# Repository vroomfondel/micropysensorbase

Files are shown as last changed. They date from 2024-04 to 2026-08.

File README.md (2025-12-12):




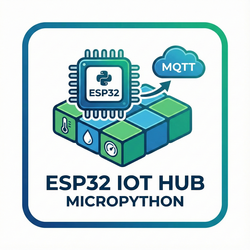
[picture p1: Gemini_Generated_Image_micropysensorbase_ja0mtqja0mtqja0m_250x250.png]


# Some esp32 micropython sensor projectbase

Project containing base-logic / configurable boilerplate for connecting sensors via esp32 via mqtt to nodered/whatever

## Description

Initial/Main project goal was to setup a device (or to be precise a couple of those) to be put in drainage 
systems in the field(s) to monitor the water-levels in the drainage system shafts and thus the proper functioning 
of the drainage pumps and their triggering.

### Extended description

This repository provides a reusable MicroPython-based foundation for building ESP32 sensor nodes that publish
telemetry to an MQTT broker for downstream processing in Node-RED, time-series storage (e.g., InfluxDB), and
monitoring/alerting (e.g., Uptime Kuma). The reference implementation focuses on hydrostatic water-level
monitoring for agricultural drainage shafts and pump supervision, but the architecture is intentionally modular
to support additional sensors and use-cases.

- Purpose and scope
  - Enable rapid provisioning of one or more ESP32 devices that read sensor data (current, voltage, illumination,
    custom analog values, etc.) and reliably publish messages via Wi‑Fi/MQTT.
  - Provide configuration-driven setup (Wi‑Fi, MQTT, I2C, sensor parameters) without reflashing firmware.
  - Offer an opinionated example flow for transforming and visualizing the data using Node‑RED and InfluxDB,
    as well as basic uptime/health monitoring.

- Architecture at a glance
  - Device firmware: MicroPython running on ESP32 with boot/main entry points and a small set of modules for
    connectivity, configuration, sensor I/O (e.g., INA226), and MQTT publishing.
  - Transport: MQTT (tested with Mosquitto) using topic conventions that are easy to consume from Node‑RED.
  - Backend/visualization: Example Node‑RED flows for normalization/calibration and routing to time-series
    storage and monitoring dashboards (InfluxDB, Uptime Kuma). Grafana can be added if desired.

- Hardware reference (water‑level monitoring)
  - ESP32 board with Wi‑Fi
  - INA226-based current/voltage measurement and a DC‑DC boost converter (XL6009/XL6019) to power 24 V sensors
  - Hydrostatic water level sensor (e.g., TL‑136)
  - Optional custom PCB (KiCAD files provided) and simple printed enclosure (FreeCAD/STL provided)

- Software components
  - Wi‑Fi management with retry and configurable credentials
  - MQTT client wrapper for robust publish/subscribe behavior on lossy links
  - INA226 measurement driver and helpers for shunt/expected‑amps configuration
  - Simple logging and diagnostics utilities suitable for constrained devices

- Data flow (typical)
  1) Sensor read cycle on the ESP32 collects samples (e.g., current/voltage correlated to water level)
  2) Values are formatted and published to MQTT topics
  3) Node‑RED consumes topics, applies calibration/offsets, and forwards to InfluxDB
  4) Uptime‑Kuma (or similar) monitors device and pump activity for alerting

- Configuration
  - Central JSON config (`esp32config.json` or `esp32config.local.json`) governs Wi‑Fi networks, MQTT broker
    credentials, I2C pin mapping, and sensor specifics (shunt value, expected current range, etc.).
  - Behavior can be adapted per device without code changes by distributing a device‑local JSON file.

- Reliability and operations
  - Designed to run unattended in outdoor enclosures; on boot, devices connect, read, and publish on a schedule.
  - Example Node‑RED flows include basic normalization and can be extended for fault detection.
  - Power draw of pumps can be correlated using separate smart plugs (e.g., Tasmota) to verify actuation events.

- Security considerations
  - Use unique MQTT credentials per device and, where possible, TLS‑enabled brokers.
  - Isolate the IoT network segment and restrict broker access to trusted clients.

- Extensibility
  - Add new sensors by implementing lightweight drivers and publishing to the existing topic structure.
  - Swap storage/visualization backends with minimal changes on the server side.

## Getting Started

### Dependencies

#### hydrostatic water-level monitoring :: hardware / environment
  * hydrostatic water level sensor TL-136
  * esp32
  * INA226
  * XL6009 DC-DC boost converter (TL-136 wants 24V which will be created by this converter 
    from the voltage/current supplied by the esp32's voltage(regulator))
  * wiring / breadboard / soldering iron
  * waterproof box (used this one in the end: https://www.amazon.de/gp/product/B0751QPFKM)

#### **(Update 2025-11-09)** KiCAD :: PCB :: hydrostatic water-level monitoring :: hardware / environment
  * KiCAD project files for PCB creation (used https://aisler.net/ for this): [kicad_ina226_xl6019_esp32_EXPORT.zip](PCB/kicad_ina226_xl6019_esp32_EXPORT.zip)
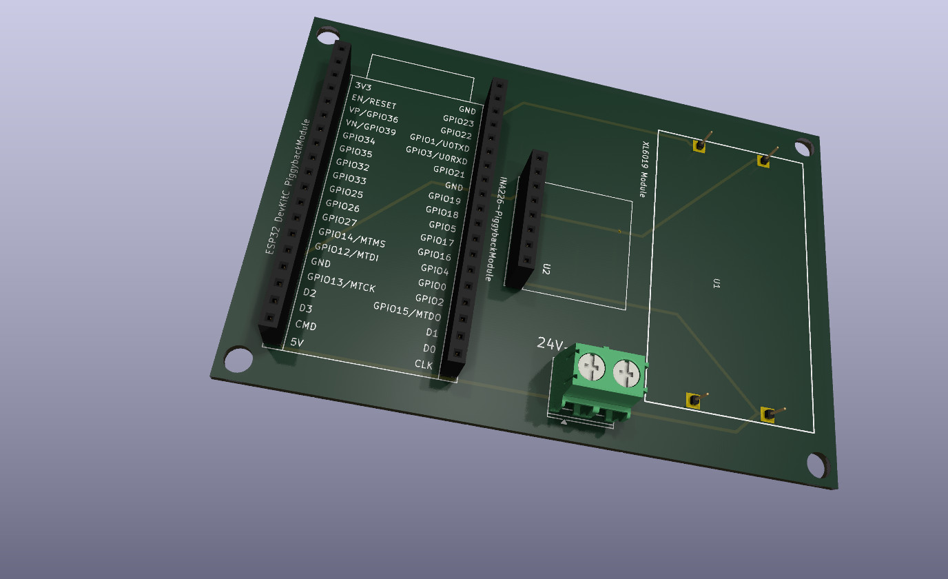
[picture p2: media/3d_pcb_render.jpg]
  * [](media/3d_pcb_render.jpg)
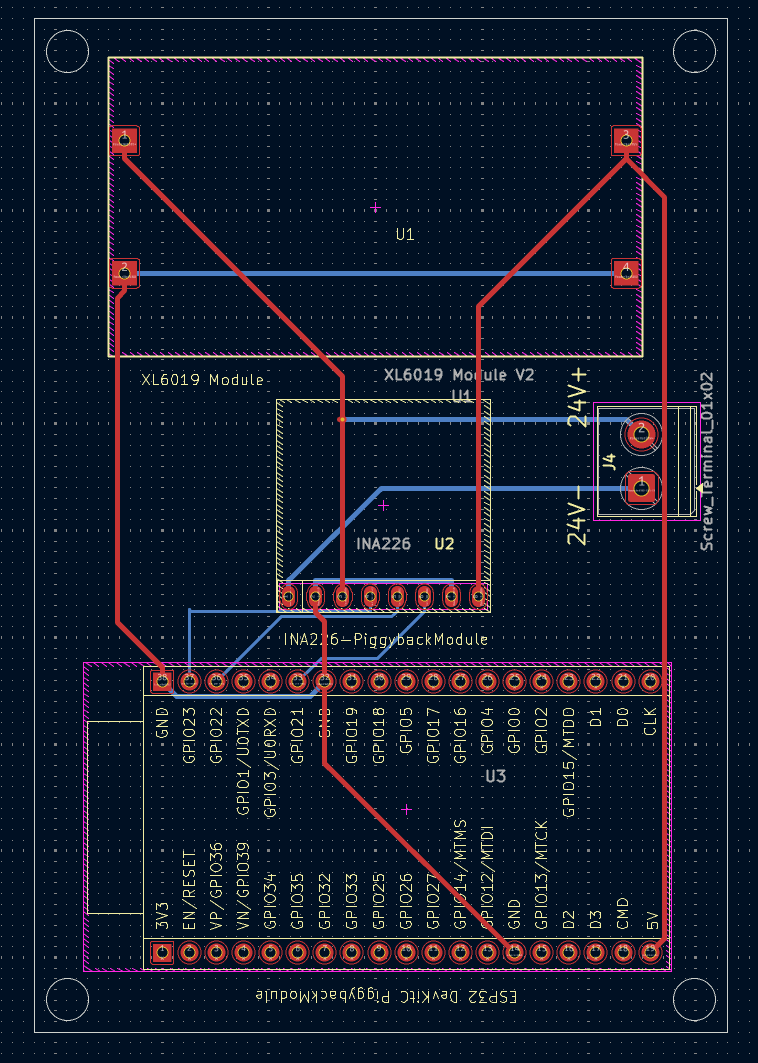
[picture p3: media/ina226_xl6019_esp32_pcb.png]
  * [](media/ina226_xl6019_esp32_pcb.png)
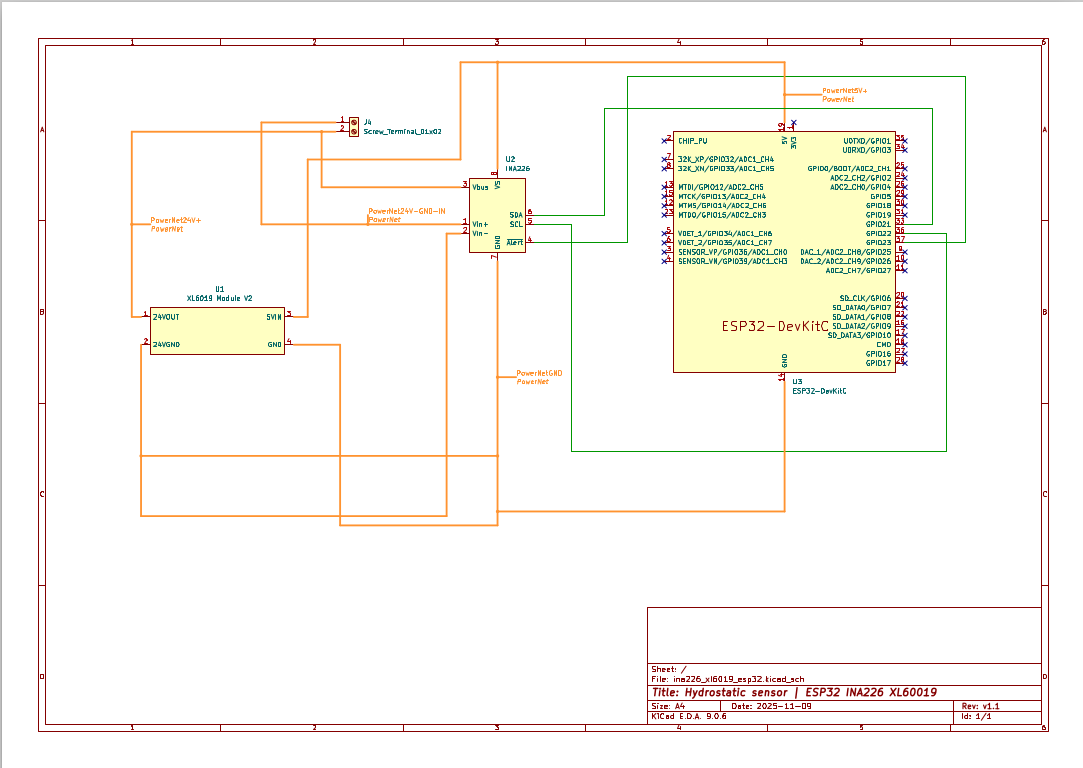
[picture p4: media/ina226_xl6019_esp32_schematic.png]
  * [](media/ina226_xl6019_esp32_schematic.pdf)
  * Received Board:<br/>
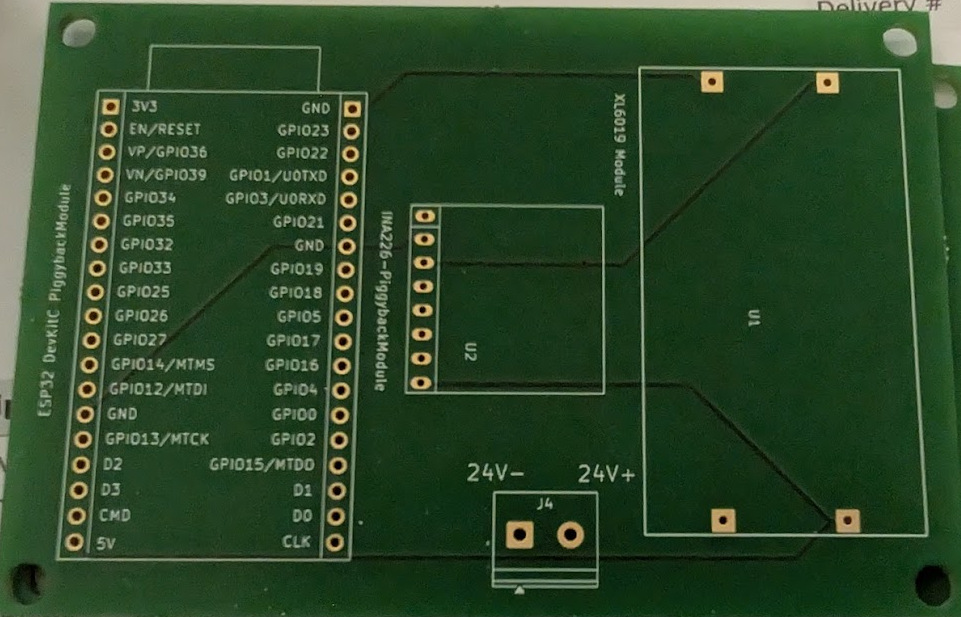
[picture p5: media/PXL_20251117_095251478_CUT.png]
    [](...)
  * Soldered+Assembled (broke one unused socket from the pin header):<br/>
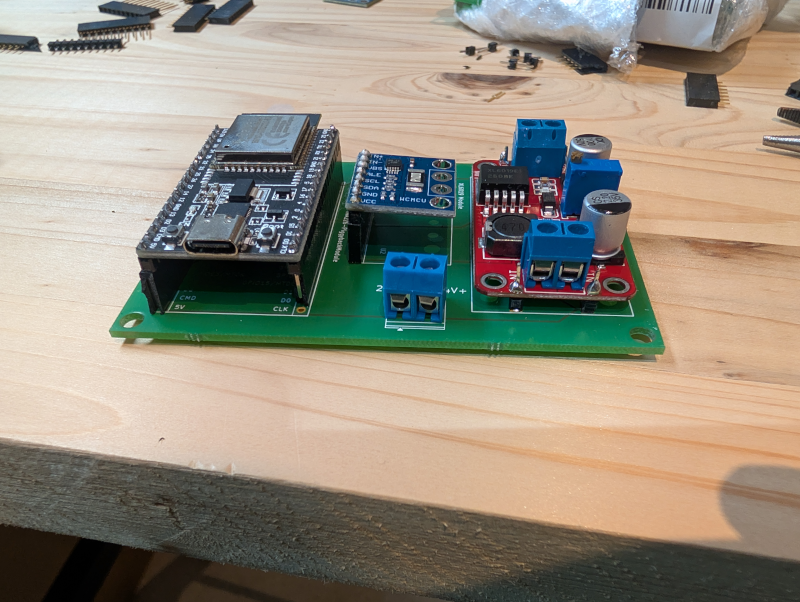
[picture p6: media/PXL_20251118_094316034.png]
    [](...)
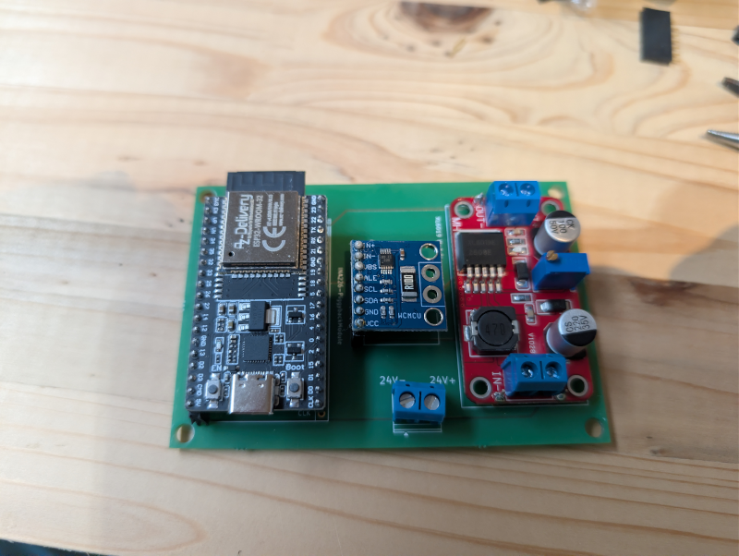
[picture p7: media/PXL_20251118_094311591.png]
    [](...)

#### **(Update 2025-11-22)** FreeCAD :: PCB :: Enclosure
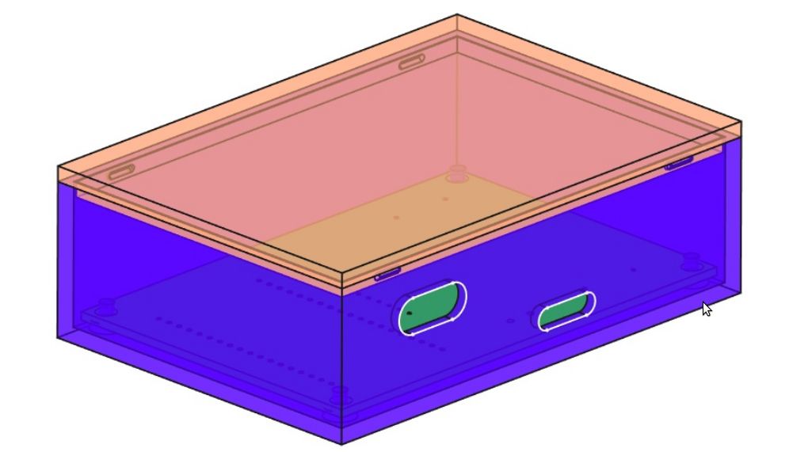
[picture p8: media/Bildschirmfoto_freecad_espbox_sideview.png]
  * [](media/esp32ina226pcbbox-sideview.pdf)
  * [esp32ina226pcbbox.FCStd](media/esp32ina226pcbbox.FCStd)
  * [esp32ina226pcbbox-BoxBase.stl](media/esp32ina226pcbbox-BoxBase.stl)
  * [esp32ina226pcbbox-BoxLid.stl](media/esp32ina226pcbbox-BoxLid.stl)

#### software / environment
  * wifi
  * installed mqtt-server (we used a local mosquitto instance for that purpose)
  * not needed, but pretty much the sense of it all: installed monitoring solution (we chose uptime-kuma)
  * installed node-red (used for some data mapping for monitoring the levels in uptime-kuma and 
    normalizing data (also used for applying "calibration"-/offset-data gathered beforehand))
  * installed influxdb (used for storing data over time and also for displaying 
    metrics (i do not really like to configure grafana - which is of course a wonderful tool))

#### Notes
* Could also be adapted to be used via esp-now -> but that would need quite hefty (but manageable) adaption 
  in regards to the mqtt-logic
* nodered-screenshot does not contains flow for monitoring the power-draw/-usage by the pumps which are connected 
  via a tasmota-enabled switchable socket (nous-A1T)

### Installing

* install a fresh version of micropython on an esp32 with wifi capabilities 
* copy over all files found in this repo to the device
* either adapt esp32config.json or create a copy of esp32config.json named as esp32config.local.json and adapt settings therein such as:
  * wifi-networks credentials
  * mqtt-broker credentials
  * enable i2c and set pins appropriately
  * enable INA226 and set shunt and expected amps appropriately 
  * create proper logic in node red/monitoring in uptime-kuma

### Executing program

* since the code is placed in boot.py and main.py just booting/resetting the esp32 should make this work

## Authors

Contributors names and contact info

* This repo's owner
* Other people mentioned/credited in the files

## Version History

* -0.42
    * there will be no proper versioning
    * earlier versions used INA219, but INA226 seems to be 
      more accurate and can additionally/also monitor voltage on the high side whilst 
      monitoring current on the low side.

## License

This project is licensed under the LGPL where applicable/possible License - see the [LICENSE.md](LICENSE.md) file for details.
Some files/part of files could be governed by different/other licenses and/or licensors, 
such as (e.g., but not limited to) [MIT](LICENSEMIT.md) | [GPL](LICENSEGPL.md) | [LGPL](LICENSELGPL.md); so please also 
regard/pay attention to comments in regards to that throughout the codebase / files / part of files.

## Acknowledgments

Inspiration, code snippets, etc.
* please see comments in files for that

## some pictures of it
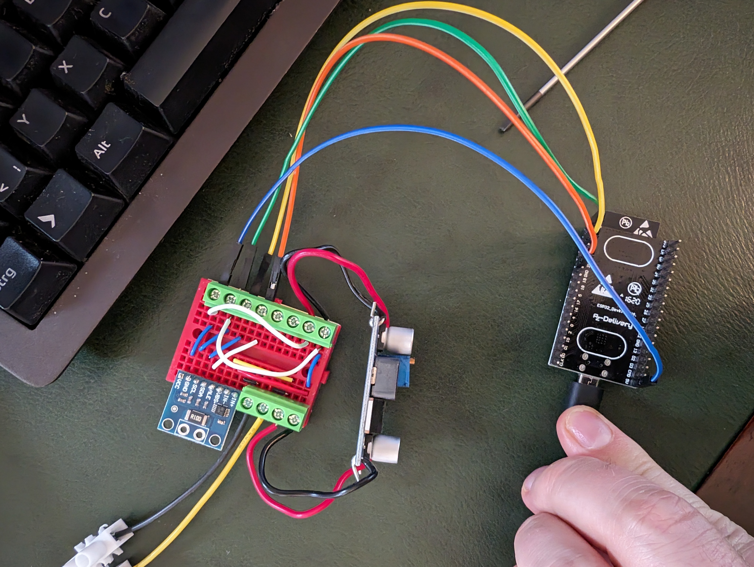
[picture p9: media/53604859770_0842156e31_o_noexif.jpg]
* [](media/53604859770_0842156e31_o_noexif.jpg)
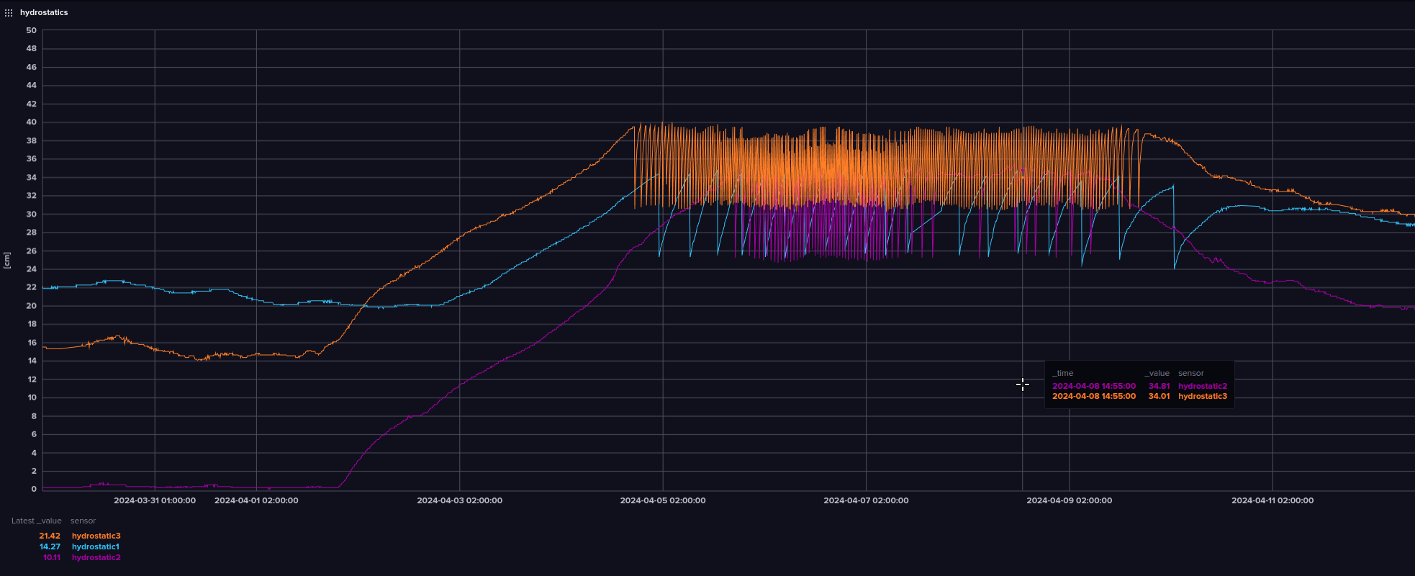
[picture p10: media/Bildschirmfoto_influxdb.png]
* [](media/Bildschirmfoto_influxdb.png)
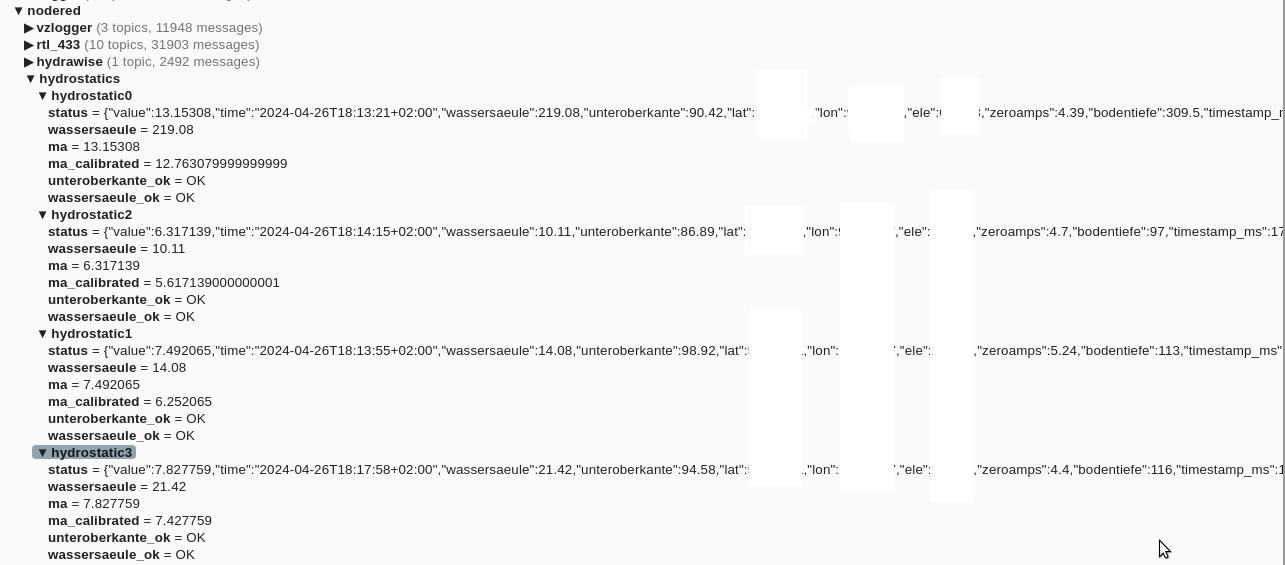
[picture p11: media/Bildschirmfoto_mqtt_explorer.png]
* [](media/Bildschirmfoto_mqtt_explorer.png)
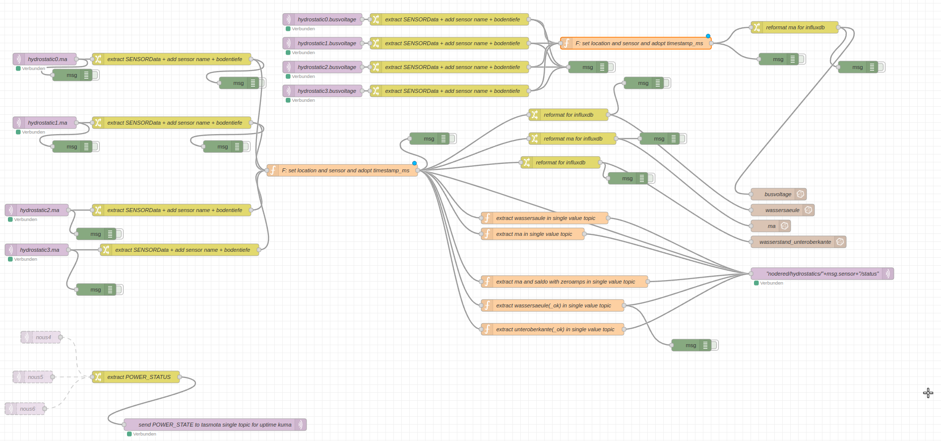
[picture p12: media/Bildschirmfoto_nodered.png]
* [](media/Bildschirmfoto_nodered.png)
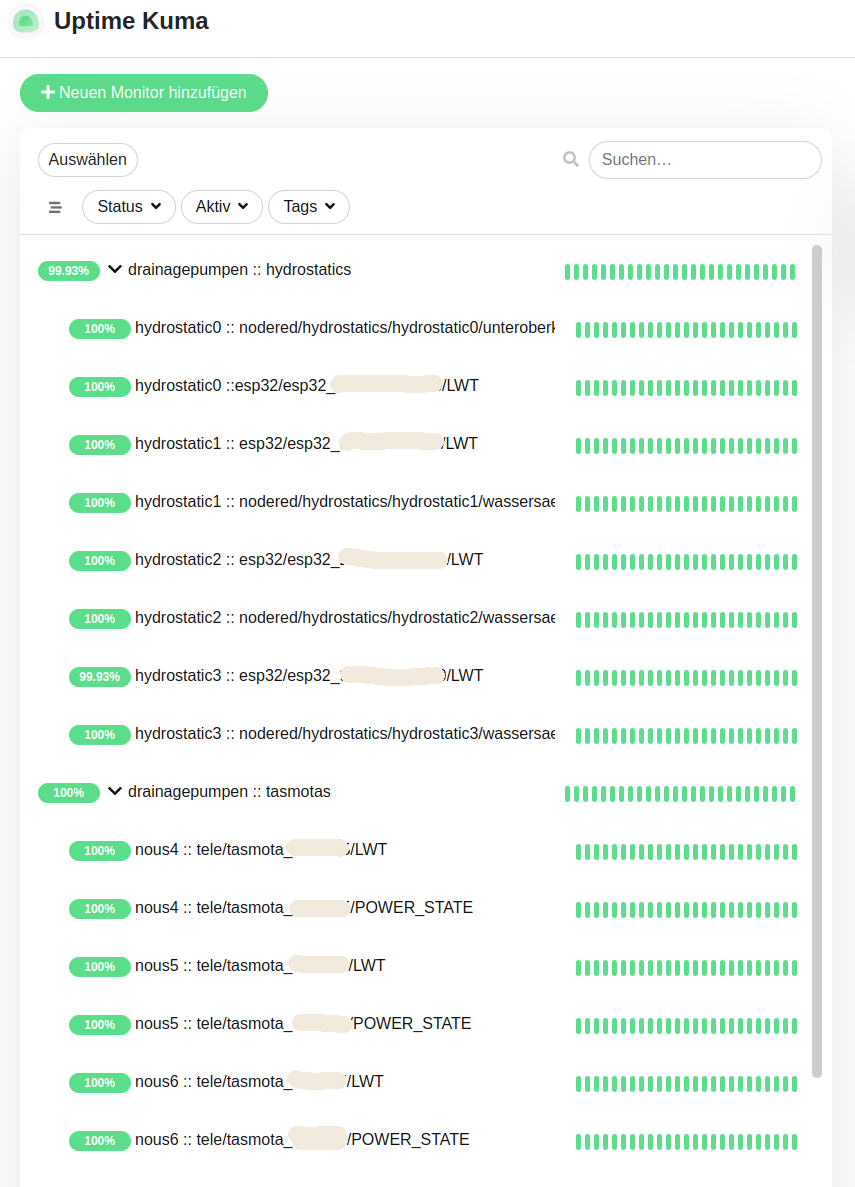
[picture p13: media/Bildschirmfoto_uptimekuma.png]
* [](media/Bildschirmfoto_uptimekuma.png)

#### btw. removing (relevant) exif-data from jpg-files should be quite easy
* ```for i in *jpg ; do exif -o ${i%.jpg}_noexif.jpg --remove $i ; done```

## TODO
* could make it pull needed files from this repo based on actual enable config-options
* exception-handling // stacktrace-printing has a lot of duplicated code throughout the codebase
* use more subflows in nodered and not just copy-paste custom-nodes :slightly_frowning_face:
* provide (fritzing?!) wiring diagram maybe ?!
* make a 3d printed enclosure which better suits the circuitry (at the moment I just 
  threw that in an plastik bag into the outdoor-box)
* make a PCB

## "Bonus content"
### tasmota-rules used on the switchable socket
* ```{"Rule1":{"State":"ON","Once":"OFF","StopOnError":"OFF","Length":258,"Free":253,"Rules":"ON Time#Minute|5 DO BackLog WebQuery http://somehost.in.the.internet.de/ GET ENDON ON WebQuery#Data=Done DO Publish stat/tasmota_112233/CONNECTIVITY OK ENDON ON WebQuery#Data$!Done DO BackLog AP 0 ; Delay 400; Publish stat/tasmota_112233/CONNECTIVITY FAILED ENDON"}}```
* ```{"Rule2":{"State":"ON","Once":"OFF","StopOnError":"OFF","Length":313,"Free":198,"Rules":"ON Power1#state=1 DO var1 ON ENDON ON Power1#state=0 DO var1 OFF ENDON ON system#boot do Backlog Power1 ON; var1 ON; Publish2 tele/tasmota_112233/POWER_STATE %var1% ENDON ON Time#Minute|1 DO Publish2 tele/tasmota_112233/POWER_STATE %var1% ENDON on Energy#Power>0 do Publish tele/tasmota_112233/POWER %value% endon"}}```
* ```{"Rule3":{"State":"ON","Once":"ON","StopOnError":"OFF","Length":216,"Free":295,"Rules":"on Energy#Power>=10 do Publish tele/tasmota_112233/POWERTRIGGER 1 endon on Energy#Power<10 do Publish tele/tasmota_112233/POWERTRIGGER 0 endon on Energy#Power<=0.001 do Publish tele/tasmota_112233/POWER %value% endon"}}```

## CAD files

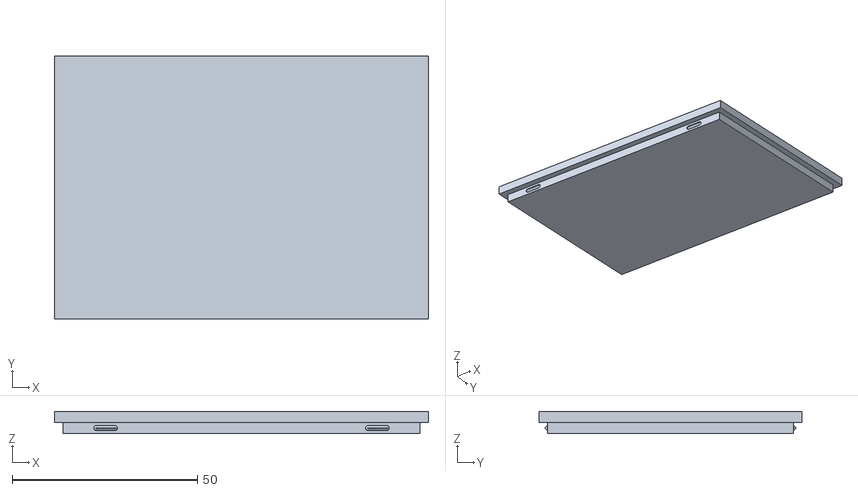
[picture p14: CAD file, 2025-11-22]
media/esp32ina226pcbbox-BoxLid.stl
101.0 x 71.0 x 6.00

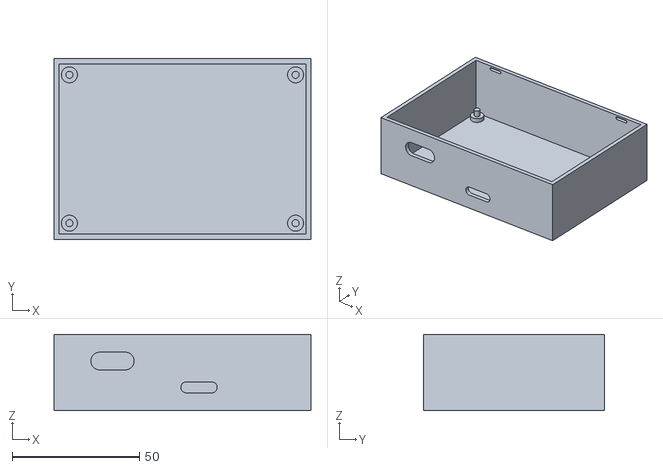
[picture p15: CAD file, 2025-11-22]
media/esp32ina226pcbbox-BoxBase.stl
101.0 x 71.0 x 30.0

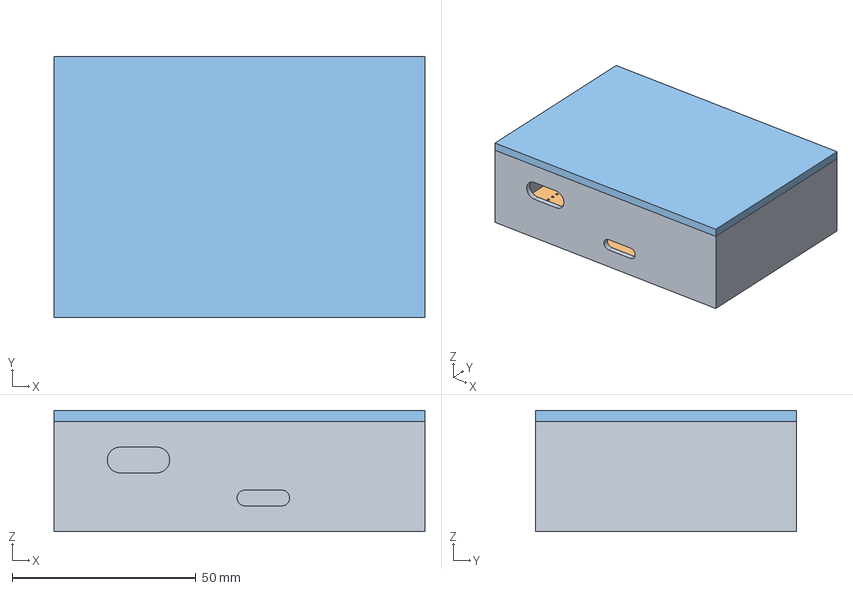
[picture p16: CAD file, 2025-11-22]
media/esp32ina226pcbbox.FCStd
101.0 x 71.0 x 33.0 mm
BoxBase
Pcb_31e5
BoxLid

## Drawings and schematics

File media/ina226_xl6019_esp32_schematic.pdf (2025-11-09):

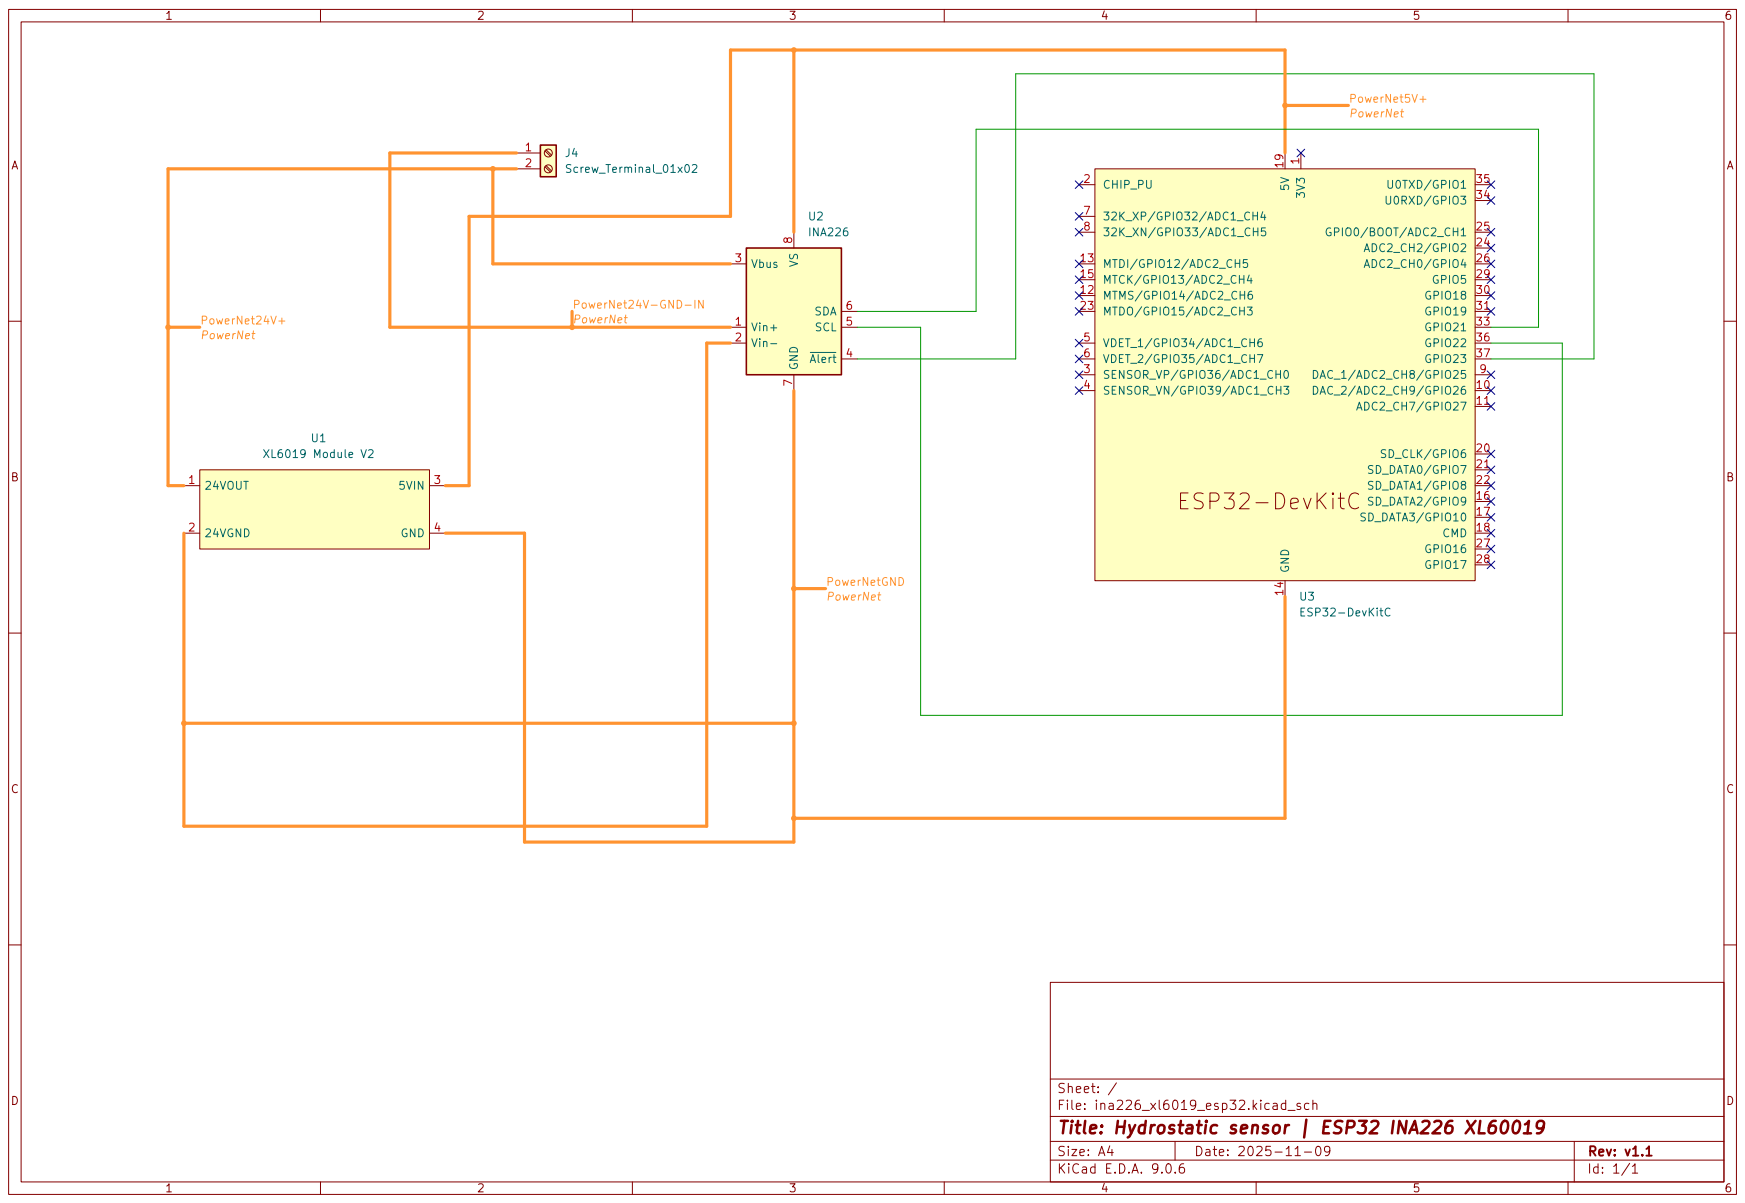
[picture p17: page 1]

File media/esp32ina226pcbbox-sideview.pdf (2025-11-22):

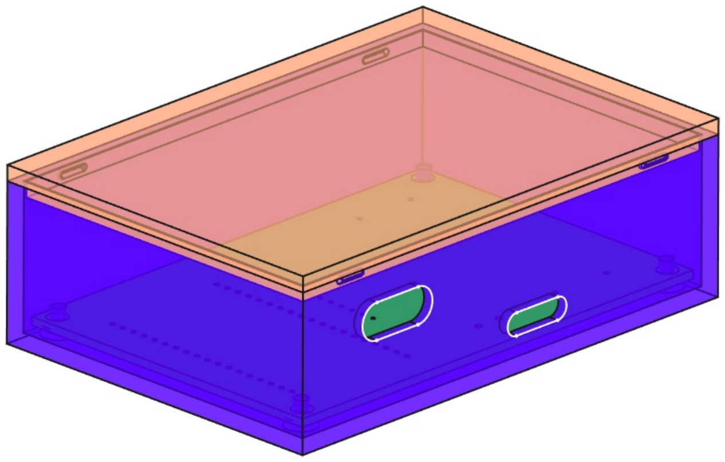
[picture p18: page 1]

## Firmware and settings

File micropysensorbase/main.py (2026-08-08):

import gc
import io
import sys

import micropython

from . import logging, time
from .time import sleep  # type: ignore[attr-defined]
from machine import Timer, WDT
import machine

from . import mqttwrap
from . import wifi
from . import config

import _thread

DISABLED_AUTO_SETUP: bool = False

logger = logging.get_logger(__name__)
logger.setLevel(logging.INFO)

if __name__ in config.get_config_data_dict(config.data, "loglevel"):
    melv: int|None = logging.get_log_level_by_name(
        config.get_config_data_str(config.get_config_data_dict(config.data, "loglevel"), "main"))
    if melv is not None:
        logger.setLevel(melv)

mainc: int = 0
logger.debug(f"main.py::{mainc}::STARTING")
mainc += 1


DISABLE_INET: bool = False

if "disable_inet" in config.data and config.get_config_data_bool(config.data, "disable_inet"):
    DISABLE_INET = True

if "disable_autosetup" in config.data:
    if config.get_config_data_bool(config.data, "disable_autosetup"):
        DISABLED_AUTO_SETUP = True
        logger.info(f"{DISABLED_AUTO_SETUP=} ENABLED")
    else:
        logger.info(f"{DISABLED_AUTO_SETUP=}")
else:
    logger.info(f"{DISABLED_AUTO_SETUP=} since not found in config")


msgtimer: Timer = Timer(0)
measuretimer: Timer = Timer(1)
reboottimer: Timer = Timer(2)
# esp32: four hardware-timers available

lock: _thread.LockType | config.DummyLock = config.DummyLock(name="main", loglevel=logging.INFO)
WATCHDOG: WDT|None = None

def reboot_callback(_: object=None) -> None:
    micropython.schedule(reboot_trigger, None)


def reboot_trigger(_: object=None) -> None:
    timestring: str = time.getisotimenow()
    logger.info(f"{timestring}::rebooting...")
    if mqttwrap is not None:
        mqttwrap.publish_one(
            topic=mqttwrap.get_feed("loggingfeed"),
            msg=f"rebooting at {timestring}",
            retain=True,
            qos=1,
            reset_if_mqtt_fails=True
        )
    machine.reset()


def check_msgs(_: object=None) -> None:
    global lock, DISABLE_INET, WATCHDOG

    if WATCHDOG:
        WATCHDOG.feed()

    if DISABLE_INET:
        return

    logger.debug("check_msgs")

    if lock.locked():
        logger.debug("main.py()::check:msgs::already LOCKED...")
        return

    acquired: bool = False
    try:
        acquired = lock.acquire()
        # timeout not implemented https://github.com/micropython/micropython/issues/3332
    except Exception as ex:
        _out = io.StringIO()
        sys.print_exception(ex)
        sys.print_exception(ex, _out)

        logger.error(_out.getvalue())

    gc.collect()

    if acquired:
        logger.debug("main.py()::check:msgs::lock acquired...")
        try:
            #with lock:
            logger.debug("main.py()::check:msgs::LOCK acquired...")
            wifi.ensure_wifi_catch_reset(reset_if_wifi_fails=True, watchdog=WATCHDOG)
            if WATCHDOG:
                WATCHDOG.feed()

            logger.debug("main.py()::check:msgs::ensuring mqtt_connect...")
            mqttwrap.ensure_mqtt_catch_reset(reset_if_mqtt_fails=True, watchdog=WATCHDOG)
            if WATCHDOG:
                WATCHDOG.feed()

            logger.debug("main.py()::check:msgs::check_msgs called...")
            mqttwrap.check_msgs(reset_if_mqtt_fails=True, watchdog=WATCHDOG)  # check for connect-error!
            if WATCHDOG:
                WATCHDOG.feed()

            ts_cmd_arg: tuple[int, str, str | None] | None

            while True:
                logger.debug("main.py()::check:msgs::while...")
                ts_cmd_arg = mqttwrap.pop_cmd_received()
                if ts_cmd_arg is None:
                    break

                cmd: str = ts_cmd_arg[1]
                if cmd == "reboot" or cmd == "reset":
                    logger.info("reboot command received...")
                    reboot_trigger()
                elif cmd == "switchap":
                    logger.info("switchap command received...")
                elif cmd == "rescanwifi":
                    logger.info("rescanwifi command received...")
                else:
                    logger.warning(f"unknown command: {cmd} arg={ts_cmd_arg[2]}")

        except Exception as ex:
            _out = io.StringIO()
            sys.print_exception(ex)
            sys.print_exception(ex, _out)

            logger.error(_out.getvalue())
    else:
        # not lock acquired
        logger.debug("main.py()::check:msgs::lock NOT acquired...")
        return

    lock.release()

    if WATCHDOG:
        WATCHDOG.feed()


def check_msgs_callback(_: object=None) -> None:
    global WATCHDOG
    # logger.debug(f"{type(trigger)=} {trigger=}")
    # DEBUG:__main__:type(trigger)=<class 'Timer'> trigger=Timer(0, mode=PERIODIC, period=3000)

    # feed BEFORE scheduling, like measure_callback does: once the main thread
    # blocks (e.g. a umqtt read without timeout), the schedule-queue fills up and
    # micropython.schedule() raises in here. A feed placed after it would never
    # run again, so the wdt panics 30s later instead of surviving the stall.
    if WATCHDOG:
        WATCHDOG.feed()

    micropython.schedule(check_msgs, None)

############################# end of boilerplate #############################

logger.debug(f"main.py::{mainc}::After boilerplate")
mainc += 1

# MEASURE_TELE_PERIOD: int = 300
MEASURE_TELE_PERIOD_S: int = 60
CHCKMSGS_PERIOD_MS: int = 3_000
MEASURETIMER_PERIOD_MS: int = 10_000

if "measure_tele_period_s" in config.data:
    MEASURE_TELE_PERIOD_S = config.get_config_data_int(config.data, "measure_tele_period_s")
if "chckmsgs_period_ms" in config.data:
    CHCKMSGS_PERIOD_MS = config.get_config_data_int(config.data, "chckmsgs_period_ms")
if "measuretimer_period_ms" in config.data:
    MEASURETIMER_PERIOD_MS = config.get_config_data_int(config.data, "measuretimer_period_ms")

logger.debug(f"main.py::{mainc}::Before setup definition")
mainc += 1

def setup() -> None:
    global msgtimer, measuretimer, MEASURETIMER_PERIOD_MS, CHCKMSGS_PERIOD_MS
    global DISABLE_INET, WATCHDOG, lock

    if config.ENABLE_WATCHDOG:
        WATCHDOG = WDT(timeout=30_000)

    if config.ENABLE_LOCK:
        lock = _thread.allocate_lock()

    logger.debug("main::setup()")

    check_msgs()

    if WATCHDOG:
        WATCHDOG.feed()

    msgtimer.init(
        period=CHCKMSGS_PERIOD_MS, mode=machine.Timer.PERIODIC, callback=check_msgs_callback
    )

    # better put that classes
    from . import measurements
    measurements.WATCHDOG = WATCHDOG
    if config.ENABLE_LOCK:
        measurements.lock = _thread.allocate_lock()

    measurements.DISABLE_INET = DISABLE_INET

    import micropython

    micropython.mem_info()
    # A failing sensor-setup must not pass for a healthy device: msgtimer and mqtt are
    # already running at this point, so an uncaught exception here leaves the node
    # reporting ONLINE with a growing runtime while it silently never measures anything.
    # Swallow it, but make the failure loud on the logging-feed.
    try:
        measurements.setup_pins()
    except Exception as ex:
        _out = io.StringIO()
        sys.print_exception(ex)
        sys.print_exception(ex, _out)

        logger.error(_out.getvalue())

        if not DISABLE_INET:
            try:
                mqttwrap.publish_one(
                    topic=mqttwrap.get_feed("loggingfeed"),
                    msg=f"SETUP_PINS FAILED at {time.getisotimenow()}: {ex}",
                    retain=True,
                    qos=1,
                    reset_if_mqtt_fails=False,
                )
            except Exception as pex:
                logger.error(f"could not publish setup_pins-failure: {pex}")
    micropython.mem_info()


    if WATCHDOG:
        WATCHDOG.feed()

    # measurement will be executed each MEASURETIMER_PERIOD_MS; MEASURE_TELE_PERIOD will be checked if "overdue";
    # also if threshold since last sent measurement is exceeeded
    # better put internals (ina etc. into method/class)
    if measurements.ina is not None or measurements.dht11 is not None or measurements.dht22 is not None:
        measuretimer.init(
            period=MEASURETIMER_PERIOD_MS, mode=machine.Timer.PERIODIC, callback=measurements.measure_callback
        )


    if config.get_config_data_int(config.data, "forcerestart_after_running_seconds") > 0:
        reboottimer.init(
            period=config.get_config_data_int(config.data, "forcerestart_after_running_seconds") * 1_000,
            mode=machine.Timer.ONE_SHOT,
            callback=reboot_callback,
        )

    # tim2 = Timer(-1)
    # tim2.init(period=30000, mode=Timer.PERIODIC, callback=lambda t: mqttclient.ping())
    # tim.deinit()

    if WATCHDOG:
        WATCHDOG.feed()

def whoami() -> str:
    ret: str = wifi.wlan.config("hostname") + "\t" + mqttwrap.boottime_local_str
    logger.info(ret)
    return ret


def setup_wifi_and_mqtt(mqtt_connect_timeout_s: int| None=30) -> None:
    global mainc

    from . import meminfo

    if not DISABLE_INET:
        logger.debug(f"main.py::{mainc}::BEFORE wifi.ensure_wifi_catch_reset()")
        mainc += 1

        wifi.ensure_wifi_catch_reset()  # without WATCHDOG for the first run!

        meminfo.main()

        logger.debug(f"main.py::{mainc}::BEFORE mqttwrap.ensure_mqtt_catch_reset()")
        mainc += 1
        mqttwrap.ensure_mqtt_catch_reset(watchdog=None, mqtt_connect_timeout_s=mqtt_connect_timeout_s)  # without WATCHDOG for the first run!

    logger.debug(f"main.py::{mainc}::After INET_CHECK")
    mainc += 1

def main() -> None:
    logger.debug("START::main.py::main()")

    import micropython

    micropython.mem_info()
    setup_wifi_and_mqtt()
    micropython.mem_info()

    if DISABLED_AUTO_SETUP:
        logger.debug("DISABLED AUTO SETUP")
    else:
        logger.debug("main.py::calling setup()")
        setup()  # also calls setup_pins
        logger.debug("main.py::setup() done.")

        logger.debug("main.py::calling import .measurements.main")

        from .measurements import main as measurements_main
        logger.debug("main.py::calling .measurements.main()")
        measurements_main()

        logger.debug("main.py::DONE::calling .measurements.main()")


    logger.debug("DONE::main::main()")


logger.debug(f"main.py::{mainc}::Before __name__ == \"__main__\"")
mainc += 1

if __name__ == "__main__":
    main()

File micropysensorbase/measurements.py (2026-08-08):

import gc
import io
import sys
from . import logging, time
import micropython
from .time import sleep  # type: ignore[attr-defined]
from machine import Timer, WDT
import machine

from . import mqttwrap
from . import wifi
from . import config

import _thread

DISABLED_AUTO_SETUP: bool = False

logger = logging.get_logger(__name__)
logger.setLevel(logging.DEBUG)

if __name__ in config.get_config_data_dict(config.data, "loglevel"):
    melv: int|None = logging.get_log_level_by_name(
        config.get_config_data_str(config.get_config_data_dict(config.data, "loglevel"), "mqttwrap"))
    if melv is not None:
        logger.setLevel(melv)

measurec: int = 0
logger.debug(f"measurements.py::{measurec}::STARTING")
measurec += 1

# will be set by call from main...
lock: _thread.LockType | config.DummyLock = config.DummyLock(name="measurements", loglevel=logging.INFO)

# will be set by call from main...
WATCHDOG: WDT|None = None

# will be set by call from main...
DISABLE_INET: bool = False

logger.debug(f"measurements.py::{measurec}::After boilerplate")
measurec += 1

import dht

from . usmbus import SMBus

soft_i2cbus: machine.SoftI2C | None = None
ssd: SH1106_I2C | SSD1306_I2C | None = None  # type: ignore

sdapin: machine.Pin | None = None
sclpin: machine.Pin | None = None

smbus_sdapin: machine.Pin | None = None
smbus_sclpin: machine.Pin | None = None

smbus: SMBus | None = None

# both are one-wire-type
dht22: dht.DHT22 | None = None
dht11: dht.DHT11 | None = None


if "boot_ssd" in config.data and config.get_config_data_bool(config.data, "boot_ssd"):
    logger.debug("boot_ssd was active... flipping from there...")
    from . import boot_ssd

    ssd = boot_ssd.ssd
    sdapin = boot_ssd.sdapin
    sclpin = boot_ssd.sclpin
    soft_i2cbus = boot_ssd.soft_i2cbus
    boot_ssd.disable()
    logger.debug("\t-> flipping done")

    # TODO HT20251130 check what happens with sdapin vs smbus_sdapin etc...

logger.debug(f"measurements.py::{measurec}::After check for boot_ssd")
measurec += 1

ina: INA226 | None = None  # type: ignore

adc_input_pin: machine.Pin | None = None
digital_input_pin: machine.Pin | None = None

wakeup_deepsleep_pin: machine.Pin | None = None

input_adc: machine.ADC | None = None

output_pin: machine.Pin | None = None

output_pin_pwm: machine.Pin | None = None
output_pwm: machine.PWM | None = None

uart2: machine.UART | None = None
pin_low: bool = False

# MEASURE_TELE_PERIOD: int = 300
MEASURE_TELE_PERIOD: int = 60

# TODO HT20251201 -> make it a map/any other container structure...
last_ina_measure_sent_gmt: float | None = None
last_dht11_measure_sent_gmt: float | None = None
last_dht22_measure_sent_gmt: float | None = None


def handle_pin_interrupt_falling_rising(arg_pin: machine.Pin) -> None:
    global pin_low
    v: float | bool | int = arg_pin.value()
    pin_low = 0 == v
    logger.debug(f"handle_pin_value :: {v} {arg_pin=}")


logger.debug(f"measurements.py::{measurec}::Before setup_pins definition")
measurec += 1


def setup_pins() -> None:
    global adc_input_pin, digital_input_pin, input_adc, pin_low, output_pin, output_pin_pwm, output_pwm, uart2
    global soft_i2cbus, sdapin, sclpin, ssd, wakeup_deepsleep_pin, smbus, ina, smbus_sdapin, smbus_sclpin, dht22, dht11

    # generally usable pins ( https://www.youtube.com/watch?v=LY-1DHTxRAk  |  https://drive.google.com/file/d/1gbKM7DA7PI7s1-ne_VomcjOrb0bE2TPZ/view )
    # 04, 05, 16, 17, 18, 19, 23, 25, 26, 27, 32, 33

    # RTC_GPIO0 (GPIO36)
    # RTC_GPIO3 (GPIO39)
    # RTC_GPIO4 (GPIO34)
    # RTC_GPIO5 (GPIO35)
    # RTC_GPIO6 (GPIO25)
    # RTC_GPIO7 (GPIO26)
    # RTC_GPIO8 (GPIO33)
    # RTC_GPIO9 (GPIO32)
    # RTC_GPIO10 (GPIO4)
    # RTC_GPIO11 (GPIO0)
    # RTC_GPIO12 (GPIO2)
    # RTC_GPIO13 (GPIO15)
    # RTC_GPIO14 (GPIO13)
    # RTC_GPIO15 (GPIO12)
    # RTC_GPIO16 (GPIO14)
    # RTC_GPIO17 (GPIO27)

    # IO34	I	GPIO34	No	RTC_GPIO04	ADC1_CH06
    # IO35	I	GPIO35	No	RTC_GPIO05	ADC1_CH07
    # SENSOR_VP	I	GPIO36	No	RTC_GPIO00	ADC1_CH0
    # SENSOR_VN	I	GPIO39	No	RTC_GPIO03	ADC1_CH03

    # UART0: tx=1, rx=3
    # UART1: tx=10, rx=9
    # UART2: tx=17, rx=16

    logger.info("Setting up pins")

    smbusc: dict[str, str | float | int | bool] = config.get_config_data_dict(config.data, "smbus")
    if config.get_config_data_bool(smbusc, "enabled"):
        if not smbus_sdapin:
            smbus_sdapin = machine.Pin(config.get_config_data_int(smbusc, "sda_pin"))
        else:
            logger.debug("smbus_sdapin already created")

        if not smbus_sclpin:
            smbus_sclpin = machine.Pin(config.get_config_data_int(smbusc, "scl_pin"))
        else:
            logger.debug("smbus_sclpin already created")

        if not smbus:
            smbus = SMBus(0, scl=smbus_sclpin, sda=smbus_sdapin, freq=400_000)
            logger.debug(f"{smbus=}")

            k: list = smbus.scan()
            for i in k:
                logger.debug(f"smbus: {i=}")
        else:
            logger.debug("smbus already created")

        ina226c: dict[str, str | float | int | bool] = config.get_config_data_dict(config.data, "ina226")
        if config.get_config_data_bool(ina226c, "enabled") and not ina:
            ina_address = 0x40
            if "address" in ina226c:
                ina_address = config.get_config_data_int(ina226c, "address")

            from . ina226_raspi import INA226
            # INA226.__init__ only computes, it never touches the bus - the first real
            # i2c-write happens in configure(). Assigning to the module-global only after
            # that succeeded, so a missing/dead chip does not leave a usable-looking
            # object behind that would let main.setup() start the measure-timer.
            _ina = INA226(
                address=ina_address,
                smbus=smbus,
                max_expected_amps=config.get_config_data_float(ina226c, "max_expected_amps"),
                log_level=logging.INFO,
                shunt_ohms=config.get_config_data_float(ina226c, "shunt_ohms")
            )
            _ina.configure(
                avg_mode=_ina.AVG_4BIT,
                bus_ct=_ina.VCT_204us_BIT,
                shunt_ct=_ina.VCT_8244us_BIT
            )  # make avg-mode configurable ?!
            ina = _ina

            # ina.configure(avg_mode=ina.AVG_1024BIT, bus_ct=ina.VCT_204us_BIT, shunt_ct=ina.VCT_8244us_BIT)  # make avg-mode configurable ?!

    i2c: dict[str, str | float | int | bool] = config.get_config_data_dict(config.data, "i2c")
    if config.get_config_data_bool(i2c, "enabled"):
        if not sdapin:
            sdapin = machine.Pin(config.get_config_data_int(i2c, "sda_pin"))
        else:
            logger.debug("sdapin already created")

        if not sclpin:
            sclpin = machine.Pin(config.get_config_data_int(i2c, "scl_pin"))
        else:
            logger.debug("sclpin already created")
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

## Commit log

2024-04-26 initial commit after rework
    [adctest.py, boot.py, boot_ssd.py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]
2024-04-26 added .scan for compatibility to i2c.scan
2024-04-26 some corrections in setup with one additon
    - corrected smbus-assignment
    - corrected rotary-dependent wakeup-pin-disable
    - added added auto setup - feature
    [main.py]
2024-12-14 Enable watchdog timer for enhanced system stability and resilience.
    handed watchdog down to mqttwrapper and wifi-helper.
    [config.py, main.py, mqttwrap.py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]
2025-10-14 Add option to send Last Will and Testament (LWT) message in `send_status_to_mosquitto` function
    ...helps with clustered/failover mqtt-server
    [mqttwrap.py]
2025-11-09 Added KiCAD project files, PCB images, and schematic for hydrostatic water-level monitoring hardware.
2025-11-17 Update README with new image of received board and include media asset
2025-11-20 Implement INA226 enhancements: address configuration, calibration methods, and measurement improvements
2025-11-20 Adjust config handling: added `data_orig` backup, modified `ndata` initialization, and updated INA226 max current to 0.05 amps.
2025-11-20 Improve NTP synchronization logic, extend watchdog timer, and increase reset delay
    - Enhanced NTP time synchronization by trying multiple hosts with improved error handling.
    - Extended watchdog timer timeout to 30 seconds for better system resilience.
    - Increased reset delay from 30s to 60s in Wi-Fi and MQTT failure scenarios.
    [boot.py, main.py, mqttwrap.py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]
2025-11-22 **Update README with FreeCAD enclosure files and associated media assets.**
    [esp32ina226pcbbox-BoxBase.stl, esp32ina226pcbbox-BoxLid.stl, esp32ina226pcbbox.FCStd]
2025-11-30 Add type hints, improve type checks, and refine configuration logic
    - Introduced type hints across most functions and variables for better code clarity and stricter error checking.
    - Replaced `ujson` with `json` for consistent JSON handling.
    - Added helper methods for retrieving typed configuration values.
    - Refined `config.py` initialization and deep-update logic.
    - Enhanced exception handling and logging for robustness.
    [boot.py, boot_ssd.py, config.py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]
2025-12-01 Add type hints, improve logging structure, and enhance error handling in `logging.py`
    - Added comprehensive type hints for functions, classes, and variables to improve code clarity and ensure stricter type checking.
    - Renamed methods to align with PEP8 conventions.
    - Improved logging structure with better formatting, file handling, and streamlined handler configuration.
    [logging.py]
2025-12-01 Fix logger method call in `wifi.py` to align with updated logging structure
    [wifi.py]
2025-12-01 Fix logger method call in `veml7700_test.py` to align with updated logging structure
    [veml7700_test.py]
2025-12-01 Fix logger method calls in `usmbus.py` to align with updated logging structure
    [usmbus.py]
2025-12-01 Fix logger method call in `mqttwrap.py` to align with updated logging structure
    [mqttwrap.py]
2025-12-01 Fix logger method call in `meminfo.py` to align with updated logging structure
    [meminfo.py]
2025-12-01 Fix logger method call in `main.py` to align with updated logging structure
    [main.py]
2025-12-01 Fix logger method calls in `ina226_raspi.py` to align with updated logging structure
    [ina226_raspi.py]
2025-12-01 Fix logger method call in `ina219.py` to align with updated logging structure
    [ina219.py]
2025-12-01 Fix logger method call in `config.py` to align with updated logging structure
    [config.py]
2025-12-01 Fix logger method call in `boot_ssd.py` to align with updated logging structure
    [boot_ssd.py]
2025-12-01 Fix logger method calls in `boot.py` to align with updated logging structure
    [boot.py]
2025-12-03 Update `esp32config.json` with new measurement settings, logging levels, MQTT feeds, and sensor configurations
2025-12-03 Add `measurements.py` to initialize and handle sensor measurements, logging, and MQTT data publishing
2025-12-03 Refactor type annotations in `sh1106.py` and `wifi.py`, clean up imports, improve error handling, and streamline configuration access
    [sh1106.py, wifi.py]
2025-12-03 Update `esp32config.json` to include `config` logging level
2025-12-03 Update `esp32config.json` to include `boot_ssd` configuration option
2025-12-03 Update `esp32config.json` to include `boot` logging level configuration
2025-12-03 Add `esp32_config.py` with comprehensive configuration classes for ESP32 functionality
2025-12-03 Add type annotations for all attributes in `esp32_config.py` to improve clarity and maintainability
2025-12-03 Replace `.mpy` files with `.py` equivalents in `package.json` and update boot instructions for repository installation.
    [boot.py]
2025-12-03 Update `package.json` to replace `.py` with `.mpy` file mappings and refine `boot.py` repository installation instructions
    [boot.py]
2025-12-05 Add `deploy_locally.sh` script for streamlined local deployment to ESP32
2025-12-05 Refactor imports for relative paths across `micropysensorbase` package, enhance logging in `config.py`, and improve `main.py` flow with better function handling and clearer logging.
2025-12-09 Add initial test scaffolding with basic pytest setup and a sample test
2026-08-08 Ensure continuous WiFi connection attempts in `migrate_flat_to_package.py` Retry indefinitely until a connection is established or max retries reached. P.S.: "Persistence beats resistance every time.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
2026-08-08 Refactor sensor initialization and handle setup errors gracefully. Ensure that any failures in setting up the pins are logged and communicated via MQTT, preventing the node from reporting as ONLINE w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
    P.S.: "The only way to do great work is to love what you do." - Steve Jobs
    [main.py, measurements.py]
2026-08-08 Add a script to migrate devices from a flat filesystem to a package-based system.
    "Serial is the safer transport: the raw REPL transfers the input as a block, so the device's own log output cannot corrupt it. Over WebREPL a firing measure-callback logs into the same session and ma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
    P.S.: "The only way to predict the future is to invent it." - Alan Kay
2026-08-08 Fix webreplcmd calling non-existent method and implement watchdog re-arming in quiesce_old_install
    P.S.: "Code is like humor. When you have to explain it, it's bad." - Cory House
    [migrate_flat_to_package.py]
2026-08-08 Refactor script to ensure consistent and robust handling of watchdog timers, feeding them before interacting with the hardware. This ensures that the device remains responsive during critical operati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
    "Programmers are not meant to understand what a computer does, they're only meant to know how to type commands." - Paul Graham
    P.S.: Always trust your stack trace; it's telling you where to look!
